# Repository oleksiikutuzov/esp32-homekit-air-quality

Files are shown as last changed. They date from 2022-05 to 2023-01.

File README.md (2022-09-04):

# ESP32 HomeKit Air Quality Sensor
Native Apple HomeKit via ESP32 for the IKEA VINDRIKTNING PM2.5 Air Quality sensor + MH-Z19B CO2 Sensor



The modification doesn't interfere with the VINDRIKTNING device itself. It just reads out data and passes it to HomeKit using ESP32.

This Firmware is a Frankenstein Monster built of some other IKEA VINDRIKTNING projects from kasik96, Hypfer and ESP32 HomeKit implementation from HomeSpan.

_As usual, don't expect any warranties. I am just a hobbyist, not a professional. It works for me, but you take your own risk using it. I am not liable for any damage to your devices._

I also added the MH-Z19B CO2 Sensor, which fits into the second enclosure along with a custom PCB, which can be glued (taped) on top of the VINDRIKTNING device. It follows the existing design and should look nice (I hope). It also has an LED to show the current CO2 level.

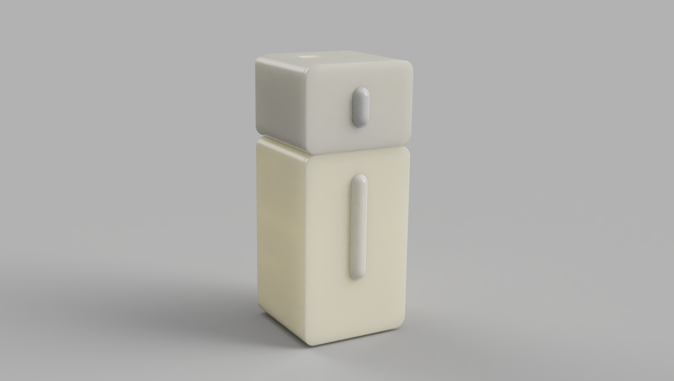
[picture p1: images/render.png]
render


## Prerequisites

- ESP-32-WROOM with project PCB
- MH-Z19B CO2 sensor
- 1 NeoPixel LED
- Some short cables
- A soldering iron
- A long PH0 Screwdriver
- Some more components (check the [BOM](https://github.com/oleksiikutuzov/esp32-homekit-air-quality/blob/main/hardware/BOM.txt))

Everything we need from the IKEA sensor is accessible via easy-to-solder test points or microcontroller pins.

## Hardware
### VINDRIKTNING

To reach the original PCB from IKEA, we need to unscrew the four visible screws in the back of the enclosure.

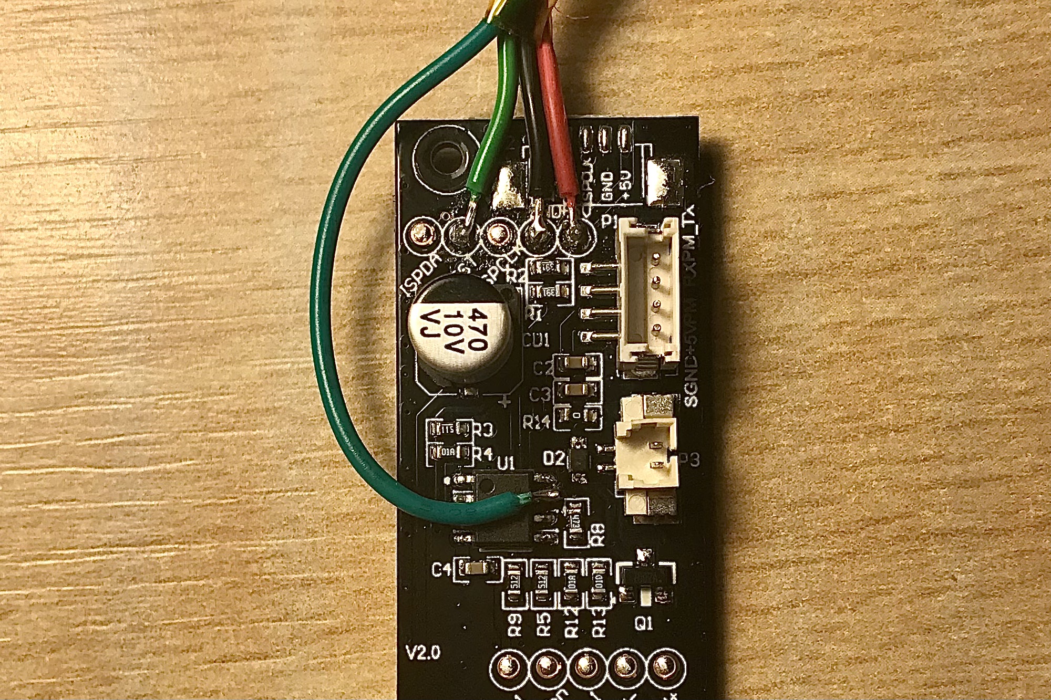
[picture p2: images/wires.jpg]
board


As you can see in this image, you'll need to solder wires to GND (black), 5V (red), and the Testpoint that is connected to the TX of the
Particle Sensor (lighter green). Additionally, you need to solder the cable to one of the pins of the microcontroller (darker green) to be able to read the values from the built-in light sensor. On my PCB I am using a JST-GH (1.25 mm) connector to connect all the wires from VINDRIKTNING. Make sure the cables from IKEA PCB have enough cross-section to carry the current because generic Chinese JST-GH connectors' cables are too thin.

Solder the custom PCB, install the MH-Z19B CO2 sensor, connect the VINDRIKTNING board and NeoPixel LED via JST connectors and you are done.

### Sensor
The PCB has pads for 1.25 mm keyless 3-pin and 4-pin JST connectors, the lid has 4 mm holes for M3 threaded inserts and holes for small screws to fix the plate on which NeoPixel is mounted.

## Software

Here you can see, which pins are used and pre-defined in the firmware:
```c++
*               ╔═════════════════════════════╗
*               ║┌─┬─┐  ┌──┐  ┌─┐             ║
*               ║│ | └──┘  └──┘ |             ║
*               ║│ |            |             ║
*               ╠═════════════════════════════╣
*           +++ ║GND                       GND║ +++
*           +++ ║3.3V                     IO23║ USED_FOR_NOTHING
*               ║                         IO22║
*               ║IO36                      IO1║ TX
*               ║IO39                      IO3║ RX
*               ║IO34                     IO21║
*               ║IO35                         ║ NC
*               ║IO32                     IO19║ MHZ TX
*               ║IO33                     IO18║ MHZ RX
*  LIGHT_SENSOR ║IO25                      IO5║
*       LED_RED ║IO26                     IO17║
*               ║IO27                     IO16║ NEOPIXEL
*  VINDRIKTNING ║IO14                      IO4║
*               ║IO12                      IO0║ BUTTONS
*               ╚═════════════════════════════╝
```

The firmware can be built and flashed using the Arduino IDE.

For this, you will need to add ESP32 support to it.

Furthermore, you will also need to install the following libraries using the Library Manager:

* Adafruit NeoPixel
* HomeSpan
* EspSoftwareSerial

And some libraries manually:

1. Go to this GitHub repo and download it as a ZIP - [AsyncElegantOTA](https://github.com/ayushsharma82/AsyncElegantOTA)
2. In Arduino IDE select "Sketch" -> "Include Library" and "Add .ZIP Library..." and select downloaded ZIP
3. Do previous steps to the following libraries:
   * [ESPAsyncWebServer](https://github.com/me-no-dev/ESPAsyncWebServer)
   * [AsyncTCP](https://github.com/me-no-dev/AsyncTCP)
   * [ErriezMHZ19B](https://github.com/Erriez/ErriezMHZ19B)
4. Download and open this repository in Arduino IDE (or VSCode with Arduino extension)
5. Set the upload speed to 115200
6. Build, flash, and you're done

Instead of Arduino IDE OTA, the web server update was implemented. You can flash binary at `http://[DEVICE IP]/update`.
There is a reboot link. Opening `http://[DEVICE IP]/reboot` will force the device to reboot.

The device can also be controlled by the button on the backside. More on [HomeSpan docs](https://github.com/HomeSpan/HomeSpan/blob/master/docs/UserGuide.md)

A list of settings variables is in the sketch. You can adjust the values up to your needs.

## Connect to HomeKit

1. Plug your Air Quality sensor to power (ESP32 is powered through VINDRIKTNING).
2. Press the button on the backside until the LED starts blinking rapidly and release it. Now it is in the configuration mode (More on [HomeSpan docs](https://github.com/HomeSpan/HomeSpan/blob/master/docs/UserGuide.md)). Press it two more times until the LED starts blinking 3 times in a row. This means mode 3 is chosen. Hold the button for 3-4 seconds once again and the WiFi AP will be started.
3. Go to WiFi settings on your iPhone/iPad and connect to the "HomeSpan-Setup" WiFi network, password `homespan`.
4. You will choose your WiFi network and set the setup code for the accessory.
5. Go to your Home app and select "Add Accessory"
6. Select "More Options" and you should see your Air Quality Sensor there.

## Prometheus metrics

The firmware creates a simple HTTP server to share the metrics to the Prometheus host server. The update interval is 10 seconds, the same as for the HomeKit data. Is available at the `http://DEVICE_IP/metrics` default port is `80`.

Installation guides for Raspberry Pi 4: [Grafana](https://pimylifeup.com/raspberry-pi-grafana/), [Prometheus](https://pimylifeup.com/raspberry-pi-prometheus/).

To add metrics to your Prometheus config:

1. Stop the Prometheus service:
```
sudo systemctl stop prometheus
```
2. Edit your config:
```
nano /home/pi/prometheus/prometheus.yml
```
Paste the following to the end of the config (Keep in mind indentation):
```
- job_name: "air_sensor"
    scrape_interval: 30s
    honor_labels: true
    static_configs:
    - targets: ['DEVICE_IP:80']
```
*Scrape interval determines, how often the server will check the device for metrics updates*

3. Start the Prometheus service again:
```
sudo systemctl start prometheus
```

## References and sources

- @kasik96 for HomeKit ESP8266 VINDRIKTNING custom firmware [GitHub link](https://github.com/kasik96/esp8266-vindriktning-particle-sensor-homekit)
- @Hypfer for MQTT ESP8266 VINDRIKTNING custom firmware [GitHub link](https://github.com/Hypfer/esp8266-vindriktning-particle-sensor)
- @HomeSpan for ESP32 HomeKit firmware [GitHub link](https://github.com/HomeSpan/HomeSpan)
- @Erriez for MH-Z19B CO2 sensor library [GitHub link](https://github.com/Erriez/ErriezMHZ19B)
- [@haxfleisch](https://twitter.com/haxfleisch) for their teardown of the device.

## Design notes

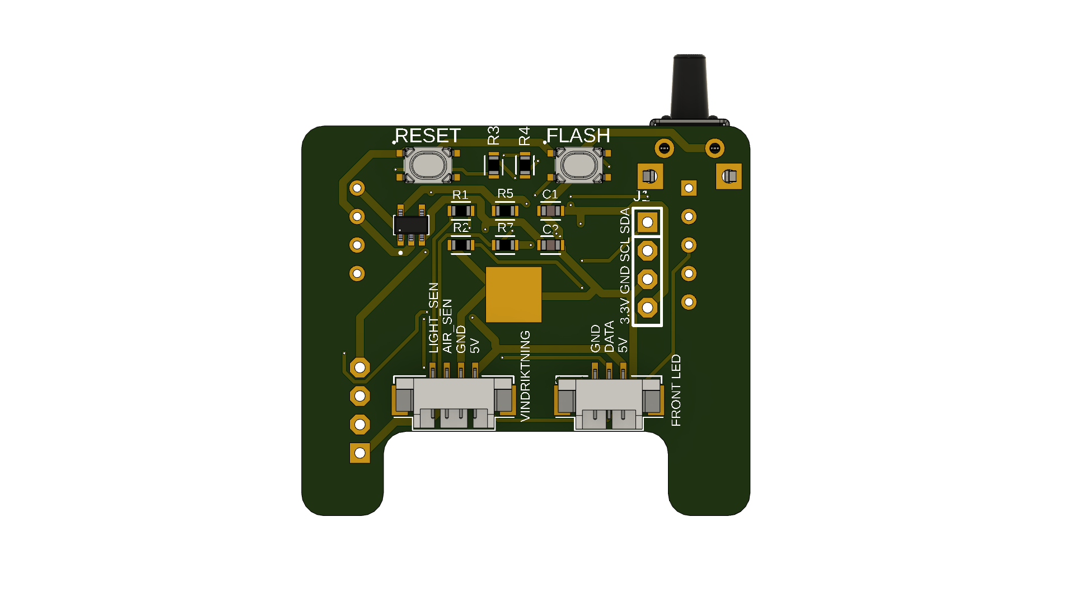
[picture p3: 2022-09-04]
hardware/V4.0/PCB_bottom_V4.0.png

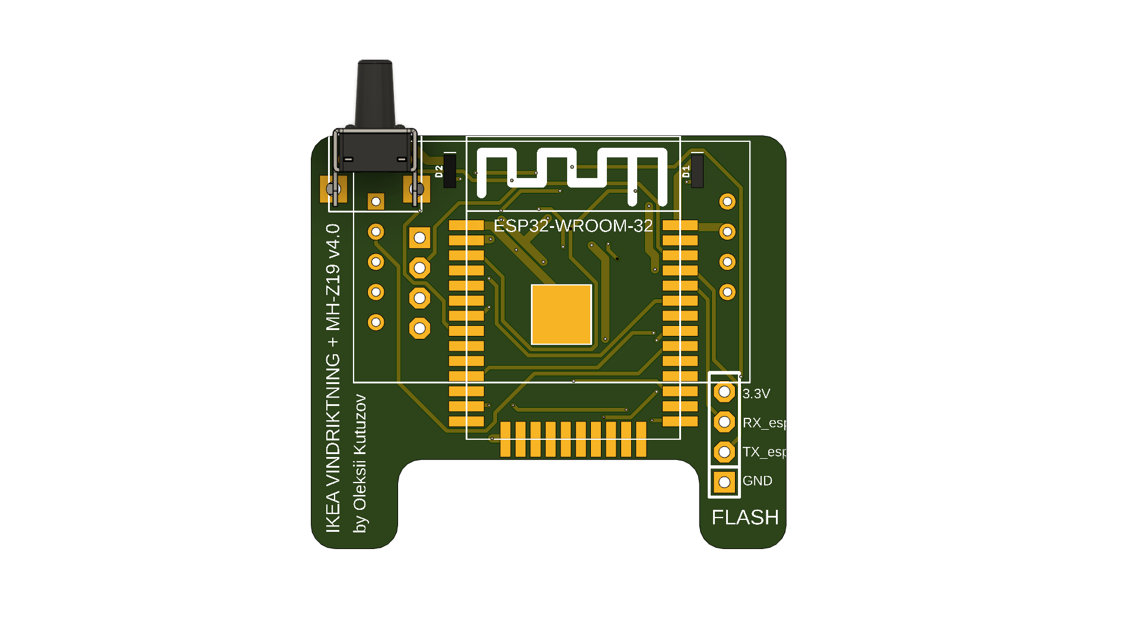
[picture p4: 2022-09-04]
hardware/V4.0/PCB_top_V4.0.png

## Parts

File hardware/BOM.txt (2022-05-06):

Part  Value                  Device                   Package          Description                                                                 
C1    10uF                   C_CHIP-0603(1608-METRIC) CAPC1608X85      Capacitor - Generic                                                         
C2    10uF                   C_CHIP-0603(1608-METRIC) CAPC1608X85      Capacitor - Generic                                                         
D2    RED                    LED-RED0603              LED-0603         Red SMD LED                                                                 
FLASH SKRPACE010             SKRPACE010               SW_SKRPACE010    Switch Tactile N.O. SPST Button J-Bend 0.05A 16VDC 2.55N SMD Automotive T/R 
J2    MH-Z19-CO2-NDIR-SENSOR MH-Z19-CO2-NDIR-SENSOR   MH-Z19           MH-Z19 - CO2 NDIR SENSOR                                                    
J3    F-1X04-SIP-100-40      F-1X04-SIP-100-40        SIP-100-04-40    FEMALE HEADER                                                               
R1    12K                    R_CHIP-0603(1608-METRIC) RESC1608X60      Resistor Fixed - Generic                                                    
R2    3K                     R_CHIP-0603(1608-METRIC) RESC1608X60      Resistor Fixed - Generic                                                    
R3    100                    R_CHIP-0603(1608-METRIC) RESC1608X60      Resistor Fixed - Generic                                                    
R4    100                    R_CHIP-0603(1608-METRIC) RESC1608X60      Resistor Fixed - Generic                                                    
R5    4.7k                   R_CHIP-0603(1608-METRIC) RESC1608X60      Resistor Fixed - Generic                                                    
R7    4.7k                   R_CHIP-0603(1608-METRIC) RESC1608X60      Resistor Fixed - Generic                                                    
RESET SKRPACE010             SKRPACE010               SW_SKRPACE010    https://a.aliexpress.com/_AWwm9c
U$1   JST-GH-4PIN            JST-GH-4PIN              JST-GH-4PIN      https://a.aliexpress.com/_9IWSRs                                                                           
U$2   JST-GH-3PIN            JST-GH-3PIN              JST-GH-3PIN      https://a.aliexpress.com/_9IWSRs                                                                           
U$3   ESP32-WROOM            ESP32-WROOM              ESP32-WROOM                                                                                 
U$4   MOMENTARY-SWITCH       MOMENTARY-SWITCH         SWITCH-MOMENTARY https://a.aliexpress.com/_AcqTm9 (6x6x6 mm)                                                                            
U1    AP2112K-3.3TRG1        AP2112K-3.3TRG1          SOT95P285X140-5N AP2112 Series 0.6 A 3.3 V Fixed Output SMT LDO Linear Regulator - SOT23-5

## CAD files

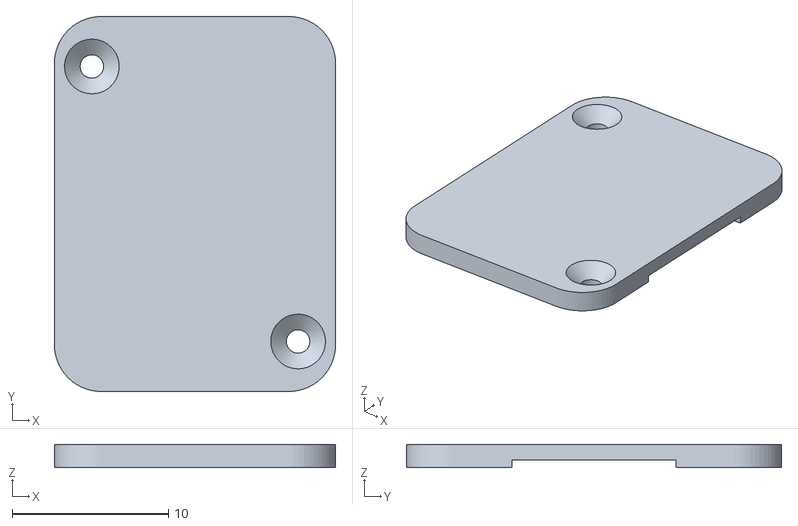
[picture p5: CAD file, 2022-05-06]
hardware/3D Printing/SENSOR_LED_Plate_V3.1.stl
18.0 x 24.0 x 1.50

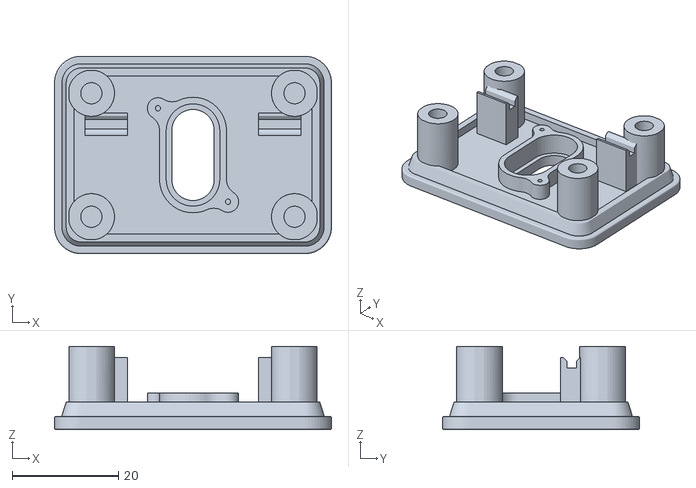
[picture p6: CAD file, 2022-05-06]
hardware/3D Printing/SENSOR_Lid_V3.1.stl
52.2 x 37.2 x 15.7

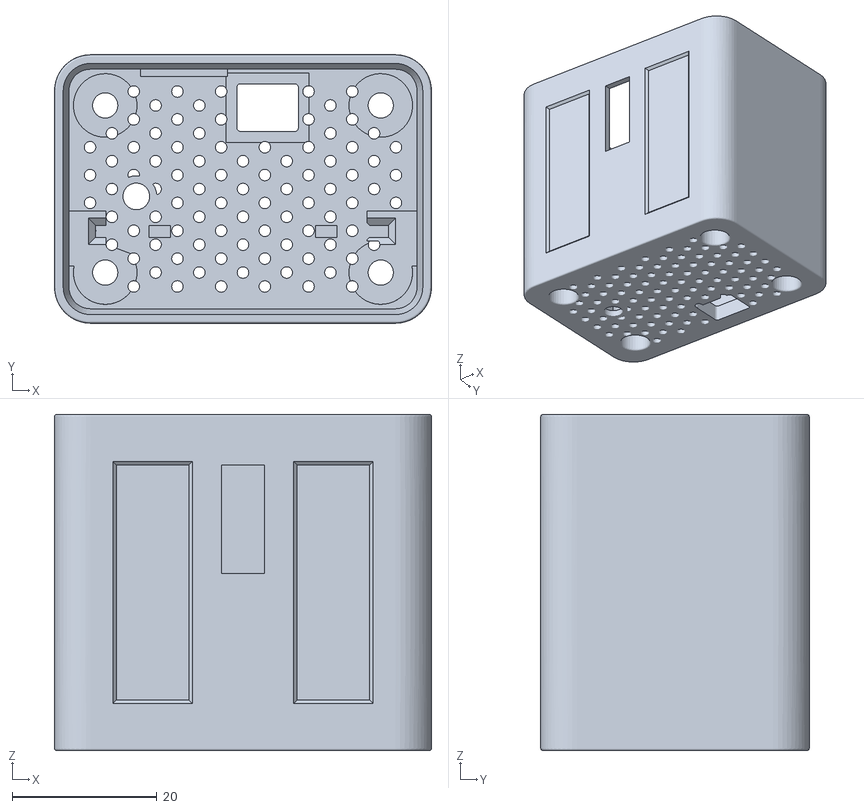
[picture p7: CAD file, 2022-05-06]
hardware/3D Printing/SENSOR_Body_V3.1.stl
52.1 x 37.1 x 46.5

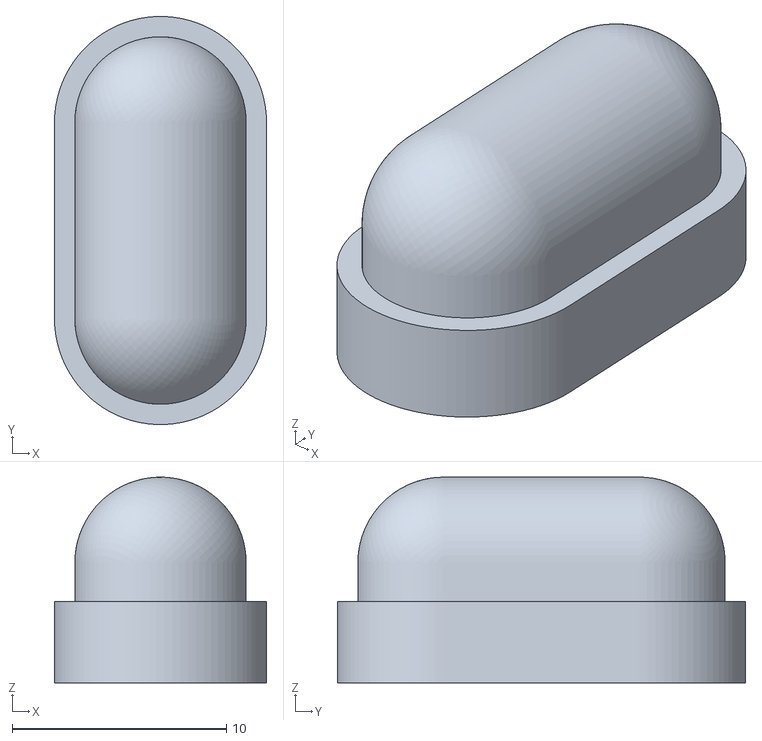
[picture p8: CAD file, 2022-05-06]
hardware/3D Printing/SENSOR_LED_Cover_V3.1.stl
9.90 x 19.0 x 9.60

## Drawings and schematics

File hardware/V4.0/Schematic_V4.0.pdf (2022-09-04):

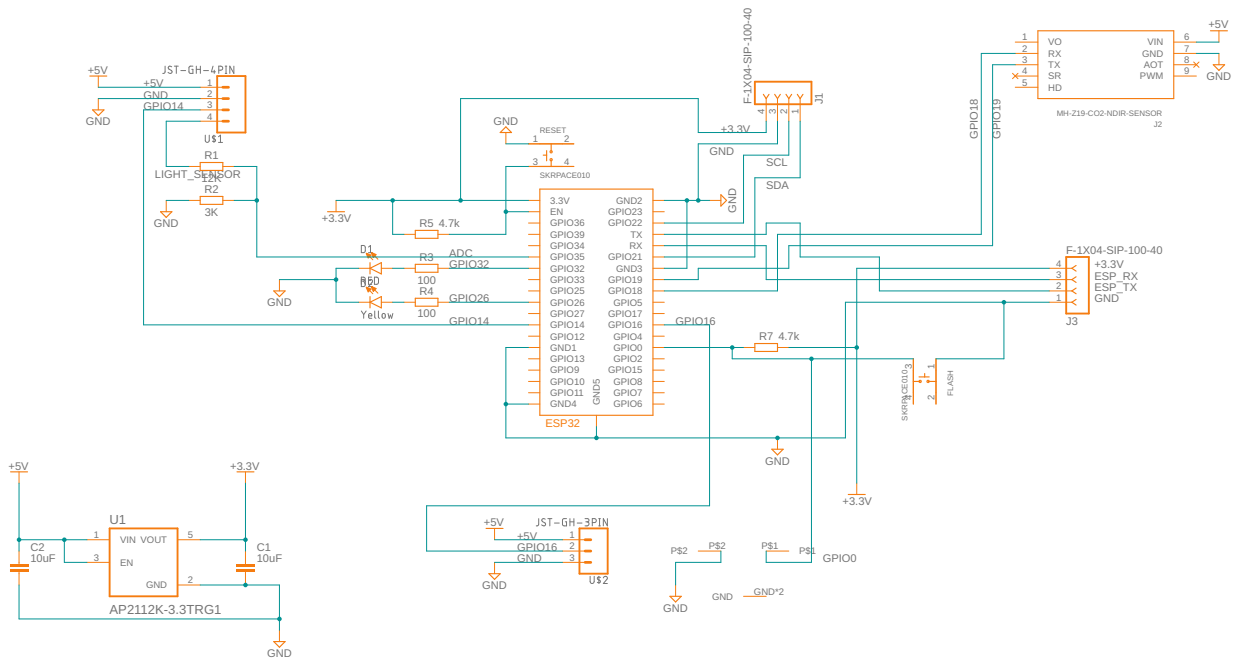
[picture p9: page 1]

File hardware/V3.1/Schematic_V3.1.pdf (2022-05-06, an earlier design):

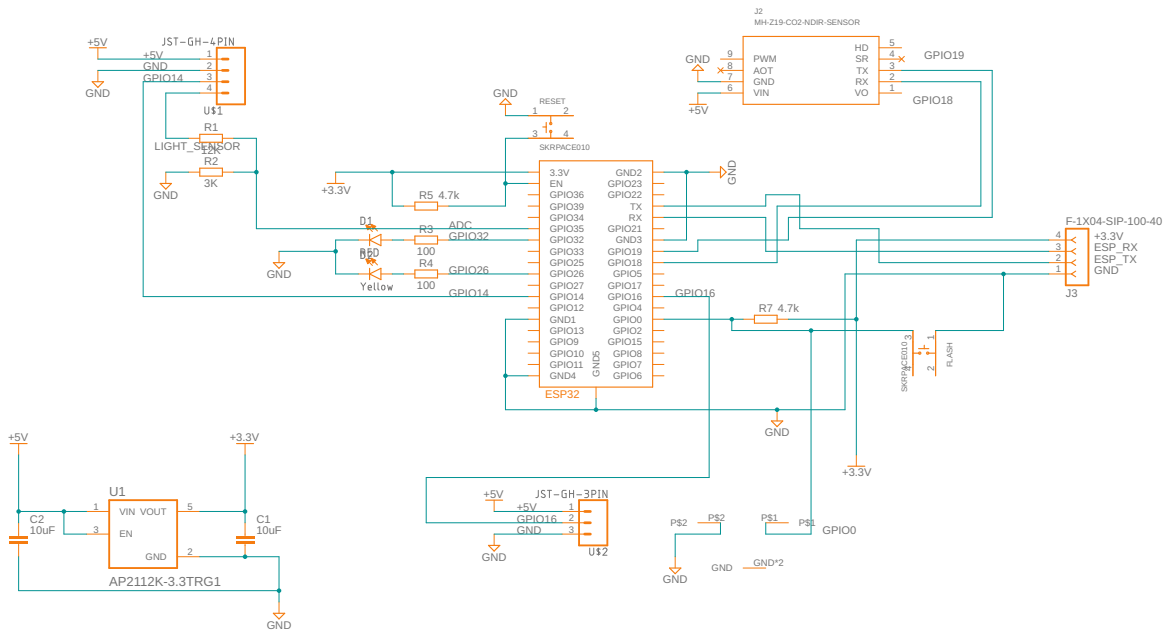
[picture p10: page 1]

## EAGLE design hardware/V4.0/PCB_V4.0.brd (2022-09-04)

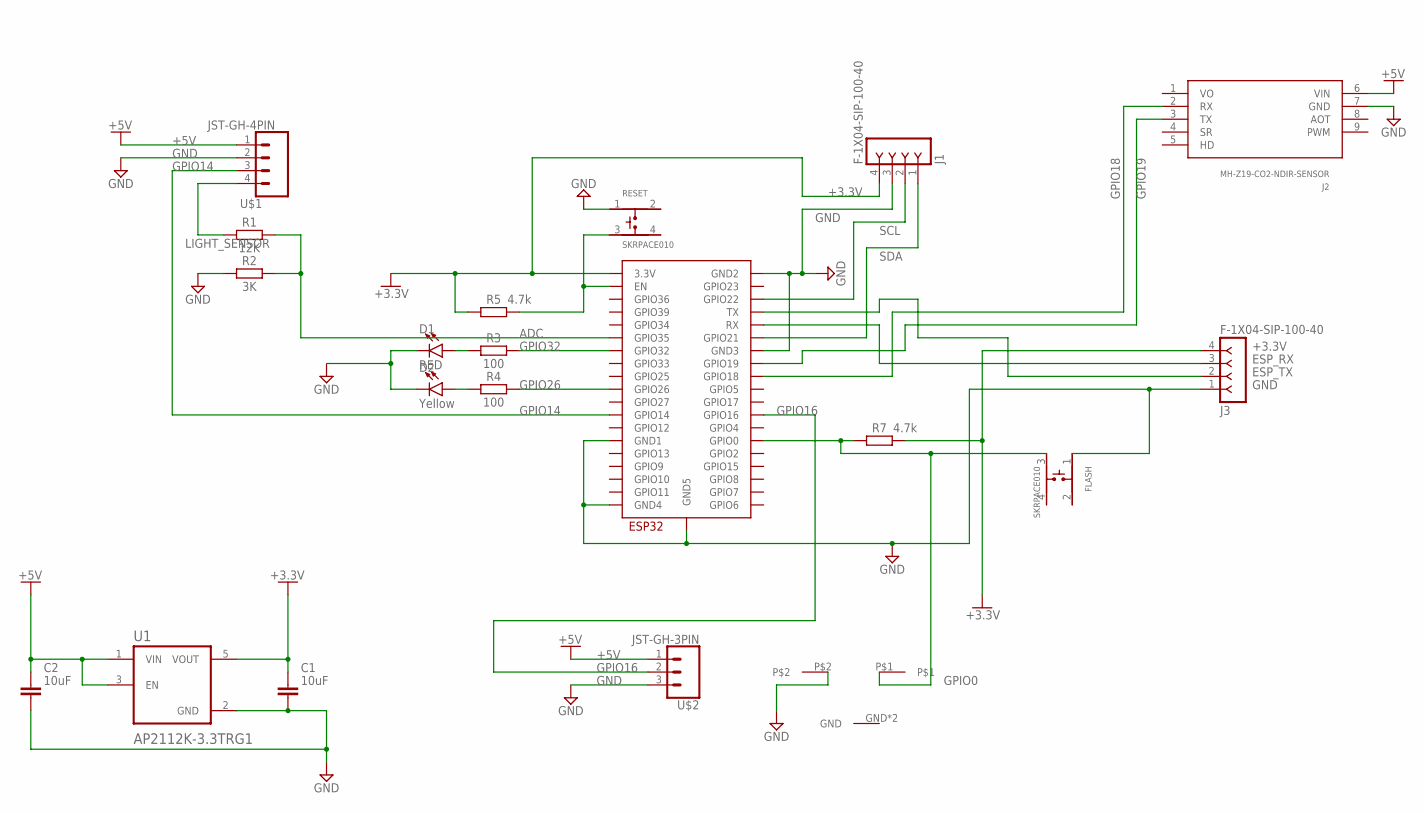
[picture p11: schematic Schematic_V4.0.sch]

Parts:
C1, C2: 10uF; CAPC1608X85
D1: RED; LED-0603
D2: Yellow; LED-0603
FLASH: SKRPACE010; SW_SKRPACE010
J1, J3: F-1X04-SIP-100-40; SIP-100-04-40
J2: MH-Z19-CO2-NDIR-SENSOR; MH-Z19
R1: 12K; RESC1608X60
R2: 3K; RESC1608X60
R3, R4: 100; RESC1608X60
R5, R7: 4.7k; RESC1608X60
RESET: SKRPACE010; SW_SKRPACE010
U1: AP2112K-3.3TRG1; SOT95P285X140-5N
U$1: JST-GH-4PIN
U$2: JST-GH-3PIN
U$3: ESP32-WROOM
U$4: MOMENTARY-SWITCH; SWITCH-MOMENTARY

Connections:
+3.3V: C1.1, J1.4, J3.4, R5.1, R7.2, U1.5 (VOUT), U$3.3V3 (3.3V)
+5V: C2.1, J2.6 (VIN), U1.1 (VIN), U1.3 (EN), U$1.1, U$2.1
ADC: R1.2, R2.2, U$3.IO35 (GPIO35)
ESP_RX: J3.3, U$3.RX
ESP_TX: J3.2, U$3.TX
GND: C1.2, C2.2, D1.C, D2.C, FLASH.1, J1.3, J2.7 (GND), J3.1, R2.1, RESET.1, U1.2 (GND), U$1.2, U$2.3, U$3.GND1, U$3.GND2, U$3.GND3, U$3.GND4, U$3.GND5, U$4.P$2
GPIO0: FLASH.3, R7.1, U$3.IO0 (GPIO0), U$4.P$1
GPIO14: U$1.3, U$3.IO14 (GPIO14)
GPIO16: U$2.2, U$3.IO16 (GPIO16)
GPIO18: J2.2 (RX), U$3.IO18 (GPIO18)
GPIO19: J2.3 (TX), U$3.IO19 (GPIO19)
GPIO26: R4.2, U$3.IO26 (GPIO26)
GPIO32: R3.2, U$3.IO32 (GPIO32)
LIGHT_SENSOR: R1.1, U$1.4
unnamed: D1.A, R3.1
unnamed: D2.A, R4.1
RESET: R5.2, RESET.3, U$3.EN
SCL: J1.2, U$3.IO22 (GPIO22)
SDA: J1.1, U$3.IO21 (GPIO21)
VO: J2.1 (VO)

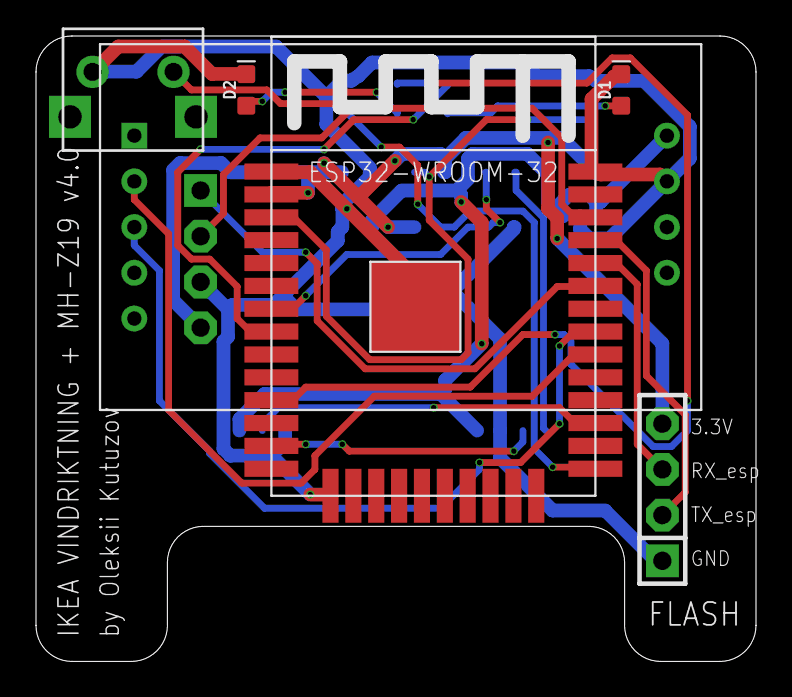
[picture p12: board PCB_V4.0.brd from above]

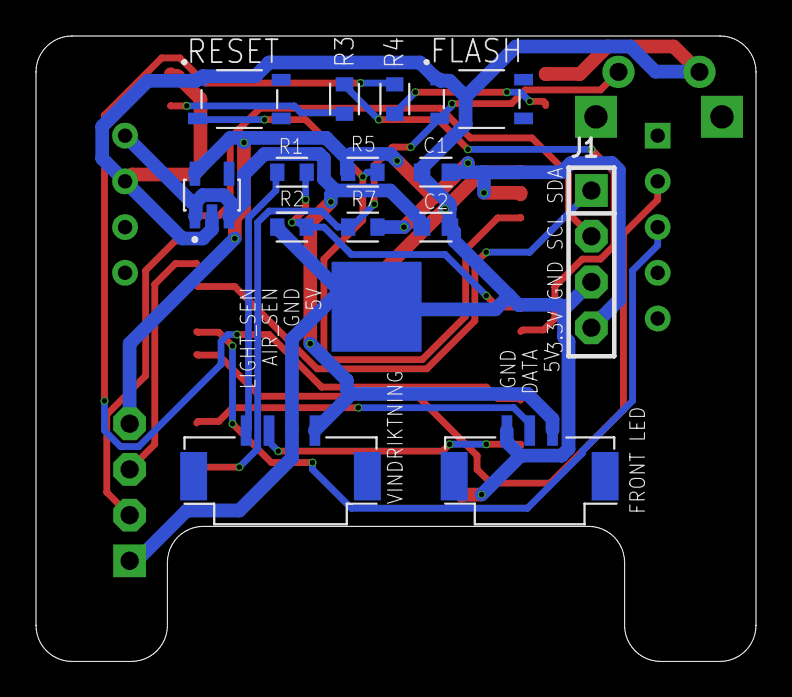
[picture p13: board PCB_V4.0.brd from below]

Board: 2 copper layers, 40.0 x 34.7 mm, 20 parts (14 on the bottom side), 19 nets.

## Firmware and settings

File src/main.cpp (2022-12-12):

/*********************************************************************************
 *  MIT License
 *
 *  Copyright (c) 2020 Gregg E. Berman
 *
 *  https://github.com/HomeSpan/HomeSpan
 *
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
 ********************************************************************************/

/*
 *                  ESP-WROOM-32 Utilized pins
 *                ╔═════════════════════════════╗
 *                ║┌─┬─┐  ┌──┐  ┌─┐             ║
 *                ║│ | └──┘  └──┘ |             ║
 *                ║│ |            |             ║
 *                ╠═════════════════════════════╣
 *            +++ ║GND                       GND║ +++
 *            +++ ║3.3V                     IO23║ USED_FOR_NOTHING
 *                ║                         IO22║ SCL
 *                ║IO36                      IO1║ TX
 *                ║IO39                      IO3║ RX
 *                ║IO34                     IO21║ SDA
 *   LIGHT_SENSOR ║IO35                         ║ NC
 *        RED_LED ║IO32                     IO19║ MHZ TX
 *                ║IO33                     IO18║ MHZ RX
 *                ║IO25                      IO5║
 *     LED_YELLOW ║IO26                     IO17║
 *                ║IO27                     IO16║ NEOPIXEL
 *   VINDRIKTNING ║IO14                      IO4║
 *                ║IO12                      IO0║ +++, BUTTONS
 *                ╚═════════════════════════════╝
 */

#define REQUIRED   VERSION(1, 6, 0)
#define FW_VERSION "1.5.0"

#include "Arduino.h"
#include "DEV_Sensors.hpp"
#include "SerialCom.hpp"
#include "Types.hpp"
#include <ElegantOTA.h>
#include <ErriezMHZ19B.h>
#include <HomeSpan.h>
#include <SoftwareSerial.h>
#include <WebServer.h>
#include <WiFiClient.h>

#define BUTTON_PIN	   0
#define LED_STATUS_PIN 26

WebServer server(80);

DEV_AirQualitySensor *AQI; // GLOBAL POINTER TO STORE SERVICE

extern "C++" bool needToWarmUp;

void setupWeb();

#if HARDWARE_VER == 4
DEV_TemperatureSensor *TEMP;
DEV_HumiditySensor	  *HUM;
#endif

void setup() {

	Serial.begin(115200);

	Serial.print("Active firmware version: ");
	Serial.println(FW_VERSION);

	String mode;
#if HARDWARE_VER == 4
	mode = "-V4 ";
#else
	mode = "-V3 ";
#endif

	String	   temp			  = FW_VERSION;
	const char compile_date[] = __DATE__ " " __TIME__;
	char	  *fw_ver		  = new char[temp.length() + 30];
	strcpy(fw_ver, temp.c_str());
	strcat(fw_ver, mode.c_str());
	strcat(fw_ver, " (");
	strcat(fw_ver, compile_date);
	strcat(fw_ver, ")");

	homeSpan.setControlPin(BUTTON_PIN);							 // Set button pin
	homeSpan.setStatusPin(LED_STATUS_PIN);						 // Set status led pin
	homeSpan.setLogLevel(1);									 // set log level
	homeSpan.setPortNum(88);									 // change port number for HomeSpan so we can use port 80 for the Web Server
	homeSpan.setStatusAutoOff(10);								 // turn off status led after 10 seconds of inactivity
	homeSpan.setWifiCallback(setupWeb);							 // need to start Web Server after WiFi is established
	homeSpan.reserveSocketConnections(3);						 // reserve 3 socket connections for Web Server
	homeSpan.enableWebLog(10, "pool.ntp.org", "UTC-1", "myLog"); // enable Web Log
	homeSpan.enableAutoStartAP();								 // enable auto start AP
	homeSpan.setSketchVersion(fw_ver);

	homeSpan.begin(Category::Sensors, "HomeSpan Air Quality Sensor");

	new SpanAccessory();
	new Service::AccessoryInformation();
	new Characteristic::Identify();
	new Characteristic::FirmwareRevision(temp.c_str());
	AQI = new DEV_AirQualitySensor(); // Create an Air Quality Sensor (see DEV_Sensors.h for definition)

#if HARDWARE_VER == 4
	new SpanAccessory();
	new Service::AccessoryInformation();
	new Characteristic::Identify();
	new Characteristic::Name("Temperature Sensor");
	TEMP = new DEV_TemperatureSensor(); // Create a Temperature Sensor (see DEV_Sensors.h for definition)

	new SpanAccessory();
	new Service::AccessoryInformation();
	new Characteristic::Identify();
	new Characteristic::Name("Humidity Sensor");
	HUM = new DEV_HumiditySensor(); // Create a Temperature Sensor (see DEV_Sensors.h for definition)
#endif
}

void loop() {
	homeSpan.poll();
	server.handleClient();
}

void setupWeb() {
	LOG0("Starting Air Quality Sensor Server Hub...\n\n");

	server.on("/metrics", HTTP_GET, []() {
		float airQuality = AQI->pm25->getVal();
		float co2		 = AQI->co2Level->getVal();
#if HARDWARE_VER == 4
		float temp = TEMP->temp->getVal<float>();
		float hum  = HUM->hum->getVal<float>();
#endif
		int	   lightness		= neopixelAutoBrightness();
		float  uptime			= esp_timer_get_time() / (6 * 10e6);
		float  heap				= esp_get_free_heap_size();
		String airQualityMetric = "# HELP air_quality PM2.5 Density\nhomekit_air_quality{device=\"air_sensor\",location=\"home\"} " + String(airQuality);
		String CO2Metric		= "# HELP co2 Carbon Dioxide\nhomekit_carbon_dioxide{device=\"air_sensor\",location=\"home\"} " + String(co2);
		String uptimeMetric		= "# HELP uptime Sensor uptime\nhomekit_uptime{device=\"air_sensor\",location=\"home\"} " + String(int(uptime));
		String heapMetric		= "# HELP heap Available heap memory\nhomekit_heap{device=\"air_sensor\",location=\"home\"} " + String(int(heap));
		String lightnessMetric	= "# HELP lightness Lightness\nhomekit_lightness{device=\"air_sensor\",location=\"home\"} " + String(lightness);
#if HARDWARE_VER == 4
		String tempMetric = "# HELP temp Temperature\nhomekit_temperature{device=\"air_sensor\",location=\"home\"} " + String(temp);
		String humMetric  = "# HELP hum Relative Humidity\nhomekit_humidity{device=\"air_sensor\",location=\"home\"} " + String(hum);
#endif
		LOG1(airQualityMetric);
		LOG1(CO2Metric);
		LOG1(uptimeMetric);
		LOG1(heapMetric);
		LOG1(lightnessMetric);
#if HARDWARE_VER == 4
		LOG1(tempMetric);
		LOG1(humMetric);
#endif
		if (needToWarmUp == 0) { // exclude co2 and air quality if it is still warming up
#if HARDWARE_VER == 4
			server.send(200, "text/plain", airQualityMetric + "\n" + CO2Metric + "\n" + uptimeMetric + "\n" + heapMetric + "\n" + lightnessMetric + "\n" + tempMetric + "\n" + humMetric);
#else
			server.send(200, "text/plain", airQualityMetric + "\n" + CO2Metric + "\n" + uptimeMetric + "\n" + heapMetric + "\n" + lightnessMetric);
#endif
		} else {
#if HARDWARE_VER == 4
			server.send(200, "text/plain", uptimeMetric + "\n" + heapMetric + "\n" + lightnessMetric + "\n" + tempMetric + "\n" + humMetric);
#else
			server.send(200, "text/plain", uptimeMetric + "\n" + heapMetric + "\n" + lightnessMetric);

#endif
		}
	});

	server.on("/reboot", HTTP_GET, []() {
		String content = "<html><body>Rebooting!  Will return to configuration page in 10 seconds.<br><br>";
		content += "<meta http-equiv = \"refresh\" content = \"10; url = /\" />";
		server.send(200, "text/html", content);

		ESP.restart();
	});

	ElegantOTA.begin(&server); // Start ElegantOTA
	server.begin();
	Serial.println("HTTP server started");
} // setupWeb

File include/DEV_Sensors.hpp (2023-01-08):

#include "SerialCom.hpp"
#include "Types.hpp"
#include "extras/Pixel.h"
#include <ErriezMHZ19B.h>
#include <HomeSpan.h>
#include <Smoothed.h>
#include <SoftwareSerial.h>

// I2C for temp sensor
#include <Wire.h>
#define si7021Addr			 0x40 // I2C address for temp sensor

#define MHZ19B_TX_PIN		 19
#define MHZ19B_RX_PIN		 18
#define INTERVAL			 10	  // in seconds
#define HOMEKIT_CO2_TRIGGER	 1350 // co2 level, at which HomeKit alarm will be triggered
#define NEOPIXEL_PIN		 16	  // Pin to which NeoPixel strip is connected
#define NUMPIXELS			 1	  // Number of pixels
#define BRIGHTNESS_DEFAULT	 20	  // Default (dimmed) brightness
#define BRIGHTNESS_MAX		 50	  // maximum brightness of CO2 indicator led
#define BRIGHTNESS_THRESHOLD 500  // TODO calibrate Threshold value of dimmed brightness
#define ANALOG_PIN			 35	  // Analog pin, to which light sensor is connected
#define SMOOTHING_COEFF		 10	  // Number of elements in the vector of previous values

#define NEOPIXEL_PIN		 16 // NeoPixel pin
#define RED_HUE				 0
#define ORANGE_HUE			 35
#define GREEN_HUE			 120

#ifndef HARDWARE_VER
#define HARDWARE_VER 3
#endif

bool				  needToWarmUp	= true;
bool				  playInitAnim	= true;
int					  tick			= 0;
bool				  airQualityAct = false;
particleSensorState_t state;
Smoothed<float>		  mySensor_co2;
Smoothed<float>		  mySensor_air;
Smoothed<float>		  mySensor_temp;
Smoothed<float>		  mySensor_hum;

// Declare functions
void   detect_mhz(Pixel *pixel);
void   fadeIn(Pixel *pixel, int h, int s, int v, double duration);
void   fadeIn(Pixel *pixel, int h, int s, int v, int brightnessOverride, double duration);
void   fadeOut(Pixel *pixel, int h, int s, int v, double duration);
void   fadeColor(Pixel *pixel, int old_hue, int new_hue, int v, double duration);
void   initAnimation(Pixel *pixel);
int	   neopixelAutoBrightness();
double getBrightness();

////////////////////////////////////
//   DEVICE-SPECIFIC LED SERVICES //
////////////////////////////////////

// Use software serial
SoftwareSerial mhzSerial(MHZ19B_TX_PIN, MHZ19B_RX_PIN);

// Declare MHZ19B object
ErriezMHZ19B mhz19b(&mhzSerial);

#if HARDWARE_VER == 4
// Custom characteristics
// clang-format off
CUSTOM_CHAR(OffsetTemperature, 00000001-0001-0001-0001-46637266EA00, PR + PW + EV, FLOAT, 0.0, -5.0, 5.0, false); // create Custom Characteristic to "select" special effects via Eve App
CUSTOM_CHAR(OffsetHumidity, 00000002-0001-0001-0001-46637266EA00, PR + PW + EV, FLOAT, 0, -10, 10, false);
// clang-format on
#endif

struct DEV_AirQualitySensor : Service::AirQualitySensor { // A standalone Air Quality sensor

	// An Air Quality Sensor is similar to a Temperature Sensor except that it supports a wide variety of measurements.
	// We will use three of them.  The first is required, the second two are optional.

	SpanCharacteristic *airQuality; // reference to the Air Quality Characteristic, which is an integer from 0 to 5
	SpanCharacteristic *pm25;

	SpanCharacteristic *co2Level;
	SpanCharacteristic *co2PeakLevel;
	SpanCharacteristic *co2StatusActive;

	Pixel *pixel;
	int	   current_hue = ORANGE_HUE;

	DEV_AirQualitySensor() : Service::AirQualitySensor() { // constructor() method

		airQuality = new Characteristic::AirQuality(1); // instantiate the Air Quality Characteristic and set initial value to 1
		pm25	   = new Characteristic::PM25Density(0);

		Serial.print("Configuring Air Quality Sensor"); // initialization message
		Serial.print("\n");

		SerialCom::setup();

		mySensor_air.begin(SMOOTHED_AVERAGE, 4); // SMOOTHED_AVERAGE, SMOOTHED_EXPONENTIAL options

		co2Level		= new Characteristic::CarbonDioxideLevel(400);
		co2PeakLevel	= new Characteristic::CarbonDioxidePeakLevel(400);
		co2StatusActive = new Characteristic::StatusActive(false);

		Serial.print("Configuring Carbon Dioxide Sensor\n"); // initialization message

		mhzSerial.begin(9600);

		pixel = new Pixel(NEOPIXEL_PIN); // creates RGB/RGBW pixel LED on specified pin using default timing parameters suitable for most SK68xx LEDs

		detect_mhz(pixel);

		// Enable auto-calibration
		mhz19b.setAutoCalibration(true);

		mySensor_co2.begin(SMOOTHED_EXPONENTIAL, SMOOTHING_COEFF); // SMOOTHED_AVERAGE, SMOOTHED_

	} // end constructor

	void loop() {

		if (pm25->timeVal() > INTERVAL * 1000) { // modify the Air Quality Characteristic every 5 seconds

			SerialCom::handleUart(state);

			if (state.valid) {

				mySensor_air.add(state.avgPM25);

				pm25->setVal(mySensor_air.get());

				int airQualityVal = 0;

				// Set Air Quality level based on PM2.5 value
				if (state.avgPM25 >= 150) {
					airQualityVal = 5;
				} else if (state.avgPM25 >= 55) {
					airQualityVal = 4;
				} else if (state.avgPM25 >= 35) {
					airQualityVal = 3;
				} else if (state.avgPM25 >= 12) {
					airQualityVal = 2;
				} else if (state.avgPM25 >= 0) {
					airQualityVal = 1;
				}
				airQuality->setVal(airQualityVal);
			}
		}

		if (playInitAnim) {
			Serial.println("Init animation");
			initAnimation(pixel);
			playInitAnim = false;
		}

		if (co2StatusActive->timeVal() > 5 * 1000 && needToWarmUp) {
			// Serial.println("Need to warm up");

			if (mhz19b.isWarmingUp()) {
				int duration = 1500;
				Serial.println("Warming up");

				fadeIn(pixel, ORANGE_HUE, 100, BRIGHTNESS_DEFAULT, duration);
				delay(1 * 1000);

				fadeOut(pixel, ORANGE_HUE, 100, BRIGHTNESS_DEFAULT, duration);
				delay(1 * 1000);

				tick = tick + 5;
				Serial.println((String)tick + " ");
				co2StatusActive->setVal(false);
			} else {
				needToWarmUp = false;
				co2StatusActive->setVal(true);
				Serial.println("Is warmed up");
			}
		}

		if (co2Level->timeVal() > INTERVAL * 1000 && !needToWarmUp) { // check time elapsed since last update and proceed only if greater than 5 seconds

			float co2_value;

			if (mhz19b.isReady()) {
				co2_value = mhz19b.readCO2();
			}

			if (co2_value >= 400) {

				// Read a sensor value
				// print co2 value
				LOG1("CO2: ");
				LOG1(co2_value);
				LOG1(" ppm\n");

				mySensor_co2.add(co2_value);

				co2Level->setVal(mySensor_co2.get()); // set the new co value; this generates an Event Notification and also resets the elapsed time
				LOG1("Carbon Dioxide Update: ");
				LOG1(co2Level->getVal());
				LOG1("\n");

				// Set color indicator
				// 400 - 800    -> green
				// 800 - 1000   -> yellow
				// 1000+        -> red
				if (co2Level->getVal() >= 1000) {
					LOG1("Red color\n");
					fadeColor(pixel, current_hue, RED_HUE, BRIGHTNESS_DEFAULT, 1000);
					current_hue = RED_HUE;
				} else if (co2Level->getVal() >= 800) {
					LOG1("Yellow color\n");
					fadeColor(pixel, current_hue, ORANGE_HUE, BRIGHTNESS_DEFAULT, 1000);
					current_hue = ORANGE_HUE;
				} else if (co2Level->getVal() >= 400) {
					LOG1("Green color\n");
					fadeColor(pixel, current_hue, GREEN_HUE, BRIGHTNESS_DEFAULT, 1000);
					current_hue = GREEN_HUE;
				}

				// Update peak value
				if (co2_value > co2PeakLevel->getVal()) {
					co2PeakLevel->setVal(co2_value);
				}
			}
		}
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

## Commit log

2022-02-11 Add reset peak value
    [DEV_Sensors.h]
2022-04-26 Add timeout for the built in led
2022-05-05 Remove unneeded pin definitions
2022-05-06 Set button pin to 0, disable auto AP
2022-05-06 Add hardware files
    [PCB_v21.brd, SENSOR_Body_v38.stl, SENSOR_LED_Cover_v5.stl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]
2022-05-17 Adjust pin scheme
2022-06-09 Apply some filtering to Air Quality Sensor data
2022-08-27 Add temperature and humidity, test brightness
2022-08-30 Add offset to temperature and humidity values
2022-08-30 Reorder hardware, upload new hardware revision
    [PCB_V3.1.brd, PCB_V4.0.brd, SENSOR_Body_V3.1.stl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]
2022-08-30 Apply smoothing to sensor data
2022-08-30 Add sensor values to prometheus metrics
2022-09-04 Switch to PlatformIO

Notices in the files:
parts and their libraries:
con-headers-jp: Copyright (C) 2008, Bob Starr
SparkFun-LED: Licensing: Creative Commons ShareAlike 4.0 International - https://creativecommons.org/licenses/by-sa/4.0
